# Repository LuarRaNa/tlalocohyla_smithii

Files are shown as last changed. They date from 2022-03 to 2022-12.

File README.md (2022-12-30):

# Tlalocohyla Smithii



These keyboards were my inspiration:

```mermaid
graph TD;
    Keyboards-->A;
    Keyboards-->C;
    A[Horizon] --> B[ChocV];
    C[Hummingbird] --> D[Rufous];
    B --> E[Smithii];
    D --> E[Smithii];
    click A "https://github.com/skarrmann/horizon" "Go to";
    click B "https://github.com/brickbots/chocV" "Go to";
    click C "https://github.com/PJE66/hummingbird" "Go to";
    click D "https://github.com/jcmkk3/trochilidae" "Go to";
```

In a nutshell...
- I really liked the Horizon/ChocV construction design and the end result of a low-profile case, just PCBs, nuts and screws.
- And I also liked the Hummingbird/Rufous 30-key layout and the awesome Xiao BLE to package a full Bluetooth keyboard powered by ZMK firmware.

<details>
<summary>How it looks like?</summary>

PXL_20221113_150954562~2

PXL_20221113_151054313~2



</details>

## BOM - WIP
|Qty|Materials|-|
|-|-|-|
|1|Main PCB|-|
|1|Bottom PCB|-|
|1|Top PCB|-|
|30|1N4148 SOD-123 diodes|-|
|30|Keycaps|-|
|30|Choc Switches V1|-|
|2|Pogo pin 5mm|[AliExpress (DHYXDD Store) - 5mm](https://es.aliexpress.com/item/1005004016701633.html)|
|1|Machined pin header|-|
|1|Seeeduino Xiao BLE|-|
|1|Li-Po battery (Optional)|I used 501240|
|5|M2 6mm Screws|[AliExpress (wuhushiyu) - 200PCS-M2 Mix - Black/White](https://www.aliexpress.com/item/32862529967.html)|
|5|M2 Nuts|See &uarr;|
|3|M2 6mm Male-Female standoffs|See &uarr;|
|1|JST-PH  male right angle connector (Optional)|-|
|1|Tact Switch (Optional, Reset)|-|
|1|MSK-12C02 (Optional, Power cut-off)|-|
|5~6|2mm tall rubber bumpons|-|

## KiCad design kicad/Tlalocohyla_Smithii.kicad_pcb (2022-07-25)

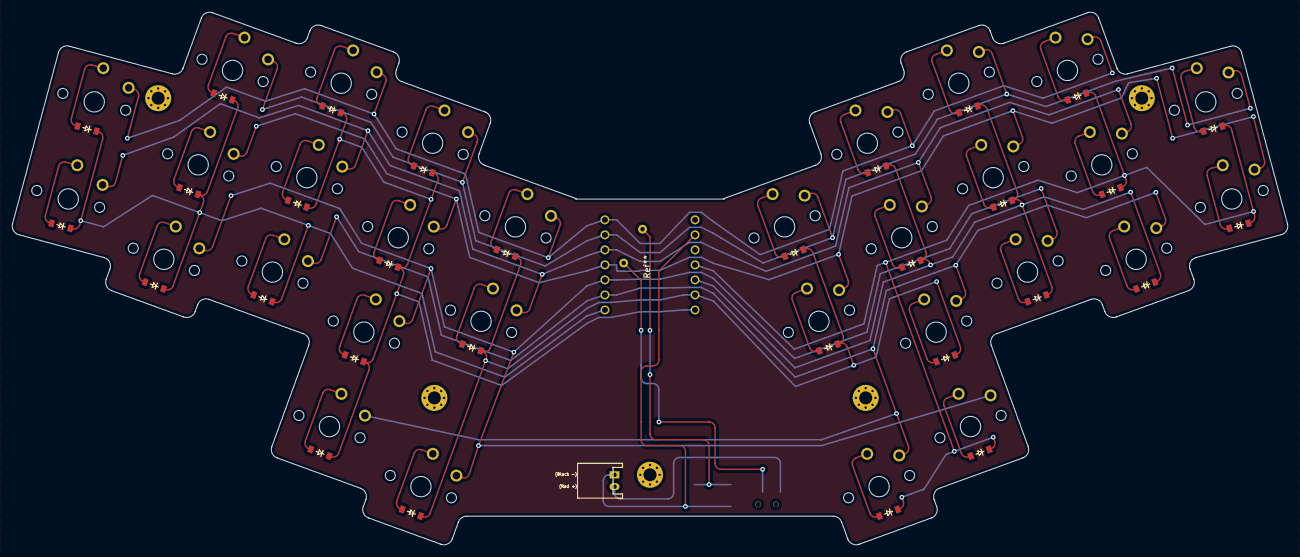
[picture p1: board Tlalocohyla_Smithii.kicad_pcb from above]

Board: 2 copper layers, 215.7 x 90.0 mm, 69 parts (0 on the bottom side), 45 nets.

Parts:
B1: SW_TACT_ALPS_SKQGABE010
D1, D2, D3, D4, D5, D6, D7, D8, D9, D10, D11, D12, D13, D14, D15, D16, D17, D18, D19, D20, D21, D22, D23, D24, D25, D26, D27, D28, D29, D30: ComboDiode
H**: Mounting_hole
H**#2, H**#3, H**#4, H**#5: Mounting_hole
JST1: JST_PH_S2B-PH-K_02x2.00mm_Angled
Ref**: Val**; Xiao BLE pogo pins
S1, S2, S3, S4, S5, S6, S7, S8, S9, S10, S11, S12, S13, S14, S15, S16, S17, S18, S19, S20, S21, S22, S23, S24, S25, S26, S27, S28, S29, S30: PG1350
T1: SPDT_C128955

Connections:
Bplus: Ref**.15, T1.2
GND_XIAO: B1.2, JST1.1, Ref**.13
JSTplus: JST1.2, T1.1
P0: Ref**.1, S2.1, S8.1, S13.1, S20.1, S26.1
P1: Ref**.2, S5.1, S11.1, S17.1, S23.1, S28.1
P2: Ref**.3, S1.1, S7.1, S12.1, S19.1, S25.1
P3: Ref**.4, S4.1, S10.1, S16.1, S22.1, S27.1
P4: Ref**.5, S3.1, S9.1, S15.1, S21.1, S29.1
P5: Ref**.6, S6.1, S14.1, S18.1, S24.1, S30.1
P6: D1.1, D2.1, D3.1, D4.1, D5.1, D6.1, Ref**.7
P7: D7.1, D8.1, D9.1, D10.1, D11.1, D14.1, Ref**.8
P8: D12.1, D13.1, D15.1, D24.1, D27.1, D28.1, Ref**.9
P9: D18.1, D21.1, D22.1, D23.1, D25.1, D26.1, Ref**.10
P10: D16.1, D17.1, D19.1, D20.1, D29.1, D30.1, Ref**.11
RST_XIAO: B1.1, Ref**.16
index_bottom: D9.2, S9.2
index_home: D10.2, S10.2
index_top: D11.2, S11.2
inner_home: D12.2, S12.2
inner_top: D13.2, S13.2
middle_bottom: D6.2, S6.2
middle_home: D7.2, S7.2
middle_top: D8.2, S8.2
mirror_index_bottom: D24.2, S24.2
mirror_index_home: D25.2, S25.2
mirror_index_top: D26.2, S26.2
mirror_inner_home: D27.2, S27.2
mirror_inner_top: D28.2, S28.2
mirror_middle_bottom: D21.2, S21.2
mirror_middle_home: D22.2, S22.2
mirror_middle_top: D23.2, S23.2
mirror_pinky_home: D16.2, S16.2
mirror_pinky_top: D17.2, S17.2
mirror_reachy_default: D30.2, S30.2
mirror_ring_bottom: D18.2, S18.2
mirror_ring_home: D19.2, S19.2
mirror_ring_top: D20.2, S20.2
mirror_tucky_default: D29.2, S29.2
pinky_home: D1.2, S1.2
pinky_top: D2.2, S2.2
reachy_default: D15.2, S15.2
ring_bottom: D3.2, S3.2
ring_home: D4.2, S4.2
ring_top: D5.2, S5.2
tucky_default: D14.2, S14.2

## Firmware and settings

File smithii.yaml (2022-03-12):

units:
  # Parameters
  # ==========
  kx: cx              # Key spacing horizontal
  ky: cy              # Key spacing vertical
  sf: 16              # Switch footprint (square)
  mirror_distance: 25 # Mirror distance
  angle: 20           # Angle between halves
  pinky_splay: 5      # Degrees of splay between pinky and ring columns
  ring_splay: 0       # Degrees of splay between ring and index columns
  visual_x: cx        # Visual representation of keycaps horizontal
  visual_y: cy        # Visual representation of keycaps vertical

points:
  rotate: -angle + pinky_splay + ring_splay
  mirror:
    ref: matrix_inner_top
    shift: [0.5sf, 0.5sf]
    distance: mirror_distance
  zones.matrix:
    key:
      tags:
        matrix: true
      footprints:
        - type: choc
          nets:
            from: =row_net
            to: =colrow
          params:
            keycaps: true
        - type: diode
          anchor:
            shift: [0, -4.7]
            rotate: 180
          nets:
            from: =colrow
            to: =column_net
          params:
            via_in_pad: true
            through_hole: false        
    rows:
      bottom.padding: ky
      home.padding: ky
      top.padding: ky
    columns.pinky:
      spread: kx
      rows:
        bottom.skip: true
        home:
          bind: [0.5ky,0.5kx,0,0]
          row_net: P2
          column_net: P6
        top:
          bind: [0,0.5kx,0.5ky,0]
          row_net: P0
          column_net: P6
        home.mirror:
          row_net: P3
          column_net: P10
        top.mirror:
          row_net: P1
          column_net: P10
    columns.ring:
      spread: kx
      stagger: 2/3ky
      rotate: -pinky_splay
      origin: [0,-3]
      rows:
        bottom:
          bind: [0.5ky,0,0,0]
          row_net: P4
          column_net: P6
        home:
          bind: [0,0.5kx,0,0]
          row_net: P3
          column_net: P6
        top:
          bind: [0,0.5kx,0.5ky,0]
          row_net: P1
          column_net: P6
        bottom.mirror:
          row_net: P5
          column_net: P9
        home.mirror:
          row_net: P2
          column_net: P10
        top.mirror:
          row_net: P0
          column_net: P10
    columns.middle:
      spread: kx
      stagger: 0.25ky
      rotate: -ring_splay
      origin: [0,-8]
      rows:
        bottom:
          bind: [0.5ky,0.5kx,0,0.5kx]
          row_net: P5
          column_net: P6
        home:
          bind: [0,0.5kx,0,0]
          row_net: P2
          column_net: P7
        top:
          bind: [0,0,0.5ky,0]
          row_net: P0
          column_net: P7
        bottom.mirror:
          row_net: P4
          column_net: P9
        home.mirror:
          row_net: P3
          column_net: P9
        top.mirror:
          row_net: P1
          column_net: P9
    columns.index:
      spread: kx
      stagger: -0.25ky
      rows:
        bottom:
          bind: [0.5ky,0,0,0]
          row_net: P4
          column_net: P7
        home:
          row_net: P3
          column_net: P7
        top:
          bind: [0,0,0.5ky,0.5kx]
          row_net: P1
          column_net: P7
        bottom.mirror:
          row_net: P5
          column_net: P8
        home.mirror:
          row_net: P2
          column_net: P9
        top.mirror:
          row_net: P0
          column_net: P9
    columns.inner:
      spread: kx
      stagger: -0.5ky
      rows:
        bottom.skip: true
        home:
          bind: [0.5ky,0,0.5ky,0.5kx]
          row_net: P2
          column_net: P8
          tags:
            center_top: true
        top:
          bind: [0,0,0.5ky,0.5kx]
          row_net: P0
          column_net: P8
          tags:
            center_top: true
        home.mirror:
          row_net: P3
          column_net: P8
        top.mirror:
          row_net: P1
          column_net: P8
  zones.thumb:
    anchor:
      ref: matrix_index_bottom
      shift: [0, -ky]
    key:
      tags:
        thumb: true
      footprints:
        - type: choc
          nets:
            from: =row_net
            to: =colrow
          params:
            keycaps: true
        - type: diode
          anchor:
            shift: [0, -4.7]
            rotate: 180
          nets:
            from: =colrow
            to: =column_net
          params:
            via_in_pad: true
            through_hole: false  
    columns.tucky:
      key:
        name: thumb_tucky
        bind: [ky, 0.5kx, 0, 0]
        row_net: P5
        column_net: P7
      key.mirror:
        row_net: P4
        column_net: P10
    columns.reachy:
      spread: kx
      stagger: -0.25ky
      key:
        name: thumb_reachy
        bind: [1.5ky, 0, 0, 0]
        row_net: P4
        column_net: P8
      key.mirror:
        row_net: P5
        column_net: P10
outlines:
  exports:
    _outer_raw:
      - type: keys
        side: left
        size: sf
      - type: keys
        side: right
        size: sf
    _center_raw:
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

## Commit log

2022-03-12 Add kicad_pcb and footprints
    [Tlalocohyla_Smithii.kicad_pcb, Tlalocohyla_Smithii_battery.kicad_pcb, Tlalocohyla_Smithii_bottom.kicad_pcb]
2022-03-17 Add filled zone
    [Tlalocohyla_Smithii_battery.kicad_pcb, Tlalocohyla_Smithii_bottom.kicad_pcb]
2022-05-03 Change Xiao footprint
    Reset and Battery plus
    [Tlalocohyla_Smithii.kicad_pcb, Tlalocohyla_Smithii_bottom.kicad_pcb]
2022-07-25 Adjust tracks
    [Tlalocohyla_Smithii.kicad_pcb]
2022-07-25 New Xiao BLE (pogo pins) footprint
2022-07-26 Add library footprints
2022-07-26 Update battery and bottom PCB
    [Tlalocohyla_Smithii_battery.kicad_pcb]
2022-11-13 Update battery and bottom PCB
    - Adjusments
    - New frog footprint
    [Tlalocohyla_Smithii_battery.kicad_pcb]
2022-11-13 Add gerber files
2022-12-19 Update README.md
    Add BOM
